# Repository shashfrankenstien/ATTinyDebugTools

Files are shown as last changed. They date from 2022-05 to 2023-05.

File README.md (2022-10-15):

# ATTiny85 Debug Tools

Arduino ISP, debugwire and charge pump based HVP for ATTiny85

-----

### This project is mostly based on code and circuits from [Wayne's Tinkering Page](https://sites.google.com/site/wayneholder/)

- [debugwire2](https://sites.google.com/site/wayneholder/debugwire2)
- [attiny-fuse-reset](https://sites.google.com/site/wayneholder/attiny-fuse-reset)
- [attiny-fuse-reset-with-12-volt-charge-pump](https://sites.google.com/site/wayneholder/attiny-fuse-reset-with-12-volt-charge-pump)

### Modified curcuit

- see AttinyDebugTools.fzz Fritzing file

<p align="center">
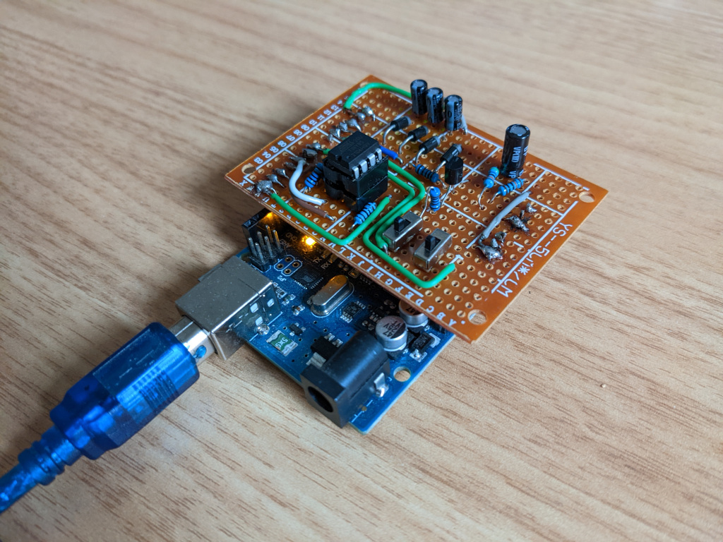
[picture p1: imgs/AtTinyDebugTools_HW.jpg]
  
</p>

### Usage

Can be started from Arduino Serial window, or using `serial_debugger.py`

```
 Commands:
  F - Identify Device & Print Fuses
  + - Enable debugWire DWEN Fuse
  - - Disable debugWire DWEN Fuse
  8 - Enable CKDIV8 (divide clock by 8)
  1 - Disable CKDIV8
  B - Engage Debugger
  < - Save Current Fuses
  > - Restore Saved Fuses
 High Voltage Programmer:
  R - Restore Saved Fuses (HVP)
  X - Hard Reset Fuses (HVP)
 Dev Commands:
  C - Send 4 Byte ISP Command
  P - Vcc On
  O - Vcc Off
```

### Also included, serial oscilloscope

- [arduino poor man's oscilloscope](https://randomnerdtutorials.com/arduino-poor-mans-oscilloscope/)

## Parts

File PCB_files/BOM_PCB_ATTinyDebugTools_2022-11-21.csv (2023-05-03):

ID | Name | Designator | Footprint | Quantity | Manufacturer Part | Manufacturer | Supplier | Supplier Part | Price | Pins | 3DModel | Contributor | Resistance (Ohms) | link
1 | 210S-1*10P L=11.6MMGold-plated black | H1 | HDR-TH_10P-P2.54-V-M-1 | 1 | B-2100S10P-A110 | Ckmtw(灿科盟) | LCSC | C124372 | 0.063 | 10 | HDR2.54-M-LI-1X10P | LCSC |  | https://item.szlcsc.com/58403.html
2 | 210-81-05GB01 | H2,H4,H3 | HDR-TH_5P-P2.54-V-M | 3 | 210-81-05GB01 | PINREX(频锐科技) | LCSC | C390676 | 0.029 | 5 | HDR-TH_5P-P2.54-M-LI-1X5P | LCSC |  | https://item.szlcsc.com/502960.html
3 | 1N4001_C2892326 | D1,D2,D3 | SOD-123FL_L2.8-W1.8-LS3.7-RD | 3 | 1N4001 | YONGYUTAI(永裕泰) | LCSC | C2892326 | 0.008 | 2 | SOD-123FL_L2.8-W1.8-LS3.7-RD | LCSC |  | https://atta.szlcsc.com/upload/public/pdf/source/20200828/C727068_03908989ABFAACA97C2BC5AF2D6316E6.pdf
4 | S8050_C2146 | Q1 | SOT-23-3_L3.0-W1.7-P0.95-LS2.9-BR | 1 | S8050 J3Y | CJ(江苏长电/长晶) | LCSC | C2146 | 0.016 | 3 | SOT-23-3L_L2.9-W1.6-H1.1-LS2.8-P0.95 | lcsc |  | https://item.szlcsc.com/139341.html
5 | 10kΩ | R1 | R0805 | 1 | 0805W8F1002T5E | UNI-ROYAL(厚声) | LCSC | C17414 | 0.001 | 2 | R0805_L2.0-W1.3-H0.6 | lcsc | 10K | https://item.szlcsc.com/142685.html
6 | 470kΩ | R2 | R0603 | 1 | 0603WAF4703T5E | UNI-ROYAL(厚声) | LCSC | C23178 | 0.001 | 2 | R0603_L1.6-W0.8-H0.8 | lcsc | 470K | https://www.mouser.in/datasheet/2/447/PYu_RT_1_to_0_01_RoHS_L_11-1669912.pdf
7 | 100kΩ | R3 | R0603 | 1 | 0603WAF1003T5E | UNI-ROYAL(厚声) | LCSC | C25803 | 0.001 | 2 | R0603_L1.6-W0.8-H0.8 | lcsc | 100K | https://www.mouser.in/datasheet/2/447/PYu_RT_1_to_0_01_RoHS_L_11-1669912.pdf
8 | 1kΩ | R4,R5,R6,R7 | R0603 | 4 | 0603WAF1001T5E | UNI-ROYAL(厚声) | LCSC | C21190 |  | 2 | R0603_L1.6-W0.8-H0.8 | lcsc | 1K | https://www.mouser.in/datasheet/2/447/PYu_RT_1_to_0_01_RoHS_L_11-1669912.pdf
9 | 220nF | C1,C2,C3 | CAP-SMD_L3.2-W1.6-RD | 3 | TAJA224K035RNJ | Kyocera AVX | LCSC | C11364 | 0.09 | 2 | CASE-A_L3.2-W1.6-H1.6 | lcsc |  | https://item.szlcsc.com/210648.html
10 | 2.2uF | C4 | CAP-SMD_L3.2-W1.6-RD | 1 | TAJA225K016RNJ | Kyocera AVX | LCSC | C7180 | 0.06 | 2 | CASE-A_L3.2-W1.6-H1.6 | lcsc |  | https://item.szlcsc.com/210648.html
11 | SS-3292S-L2-B | SW-PRG-DBG,SW-NORM-HVP | SW-SMD_SS-3292S-L2-B | 2 | SS-3292S-L2-B | XKB Enterprise | LCSC | C500057 | 0.132 | 7 | SW-SMD_SS-3292S-L2-B | LCSC |  | https://item.szlcsc.com/512183.html?ref=editor&logined=true
12 | DS1009-08AT1NX-0A2 | ATTINY | DIP-8_L10.0-W6.5-P2.54-LS7.6-BL | 1 | DS1009-08AT1NX-0A2 | CONNFLY | LCSC | C72124 | 0.031 | 8 | DIP-8_L10.0-W6.5-P2.54-LS7.6-BL | lcsc |  | https://item.szlcsc.com/241216.html

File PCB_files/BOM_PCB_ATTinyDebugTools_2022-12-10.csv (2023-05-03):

ID | Name | Designator | Footprint | Quantity | Manufacturer Part | Manufacturer | Supplier | Supplier Part | Price | Pins | 3DModel | Contributor | Resistance (Ohms) | link
1 | S4B-PH-K(LF)(SN) | I2C | CONN-TH_S4B-PH-K-LF-SN | 1 | S4B-PH-K(LF)(SN) | JST Sales America | LCSC | C265452 | 0.014 | 4 | CONN-TH_S4B-PH-K-LF-SN | LCSC |  | https://atta.szlcsc.com/upload/public/pdf/source/20180829/C265452_92616666173A3FAF5DFA68F980034548.pdf
2 | SS-3292S-L2-B | NORM-HVP,PRG-DBG | SW-SMD_SS-3292S-L2-B | 2 | SS-3292S-L2-B | XKB Enterprise | LCSC | C500057 | 0.021 | 7 | SW-SMD_SS-3292S-L2-B | LCSC |  | https://item.szlcsc.com/512183.html?ref=editor&logined=true
3 | 1N4148WS T4 | D1,D2,D3 | SOD-323_L1.8-W1.3-LS2.5-RD | 3 | 1N4148WS | CJ(江苏长电/长晶) | LCSC | C2128 | 0.002 | 2 | SOD-323_L1.7-W1.3-H1.1-LS2.5 | lcsc |  | https://item.szlcsc.com/295156.html
4 | 10kΩ | R1 | R0603 | 1 | 0603WAF1002T5E | UniOhm | LCSC | C25804 |  | 2 | R0603_L1.6-W0.8-H0.8 | lcsc | 10K | https://www.mouser.in/datasheet/2/447/PYu_RT_1_to_0_01_RoHS_L_11-1669912.pdf
5 | 220nF | C1,C2,C3 | C0603 | 3 | CL10B224KA8NNNC | SAMSUNG(三星) | LCSC | C21120 | 0.001 | 2 | C0603_L1.6-W0.8-H0.8 | lcsc |  | https://item.szlcsc.com/362304.html
6 | 2.2uF | C4 | C0603 | 1 | CL10A225KO8NNNC | SAMSUNG(三星) | LCSC | C23630 | 0.001 | 2 | C0603_L1.6-W0.8-H0.8 | lcsc |  | https://item.szlcsc.com/362304.html
7 | 1kΩ | R8,R4,R5,R6,R7 | R0603 | 5 | 0603WAF1001T5E | UNI-ROYAL(厚声) | LCSC | C21190 |  | 2 | R0603_L1.6-W0.8-H0.8 | lcsc | 1K | https://www.mouser.in/datasheet/2/447/PYu_RT_1_to_0_01_RoHS_L_11-1669912.pdf
8 | ARDUINO UNO | U1 | UNO_R3;WO ARDUINO UNO | 1 |  |  |  |  |  | 32
9 | S8050_C2146 | Q1 | SOT-23-3_L3.0-W1.7-P0.95-LS2.9-BR | 1 | S8050 J3Y | CJ(江苏长电/长晶) | LCSC | C2146 | 0.002 | 3 | SOT-23-3L_L2.9-W1.6-H1.1-LS2.8-P0.95 | lcsc |  | https://item.szlcsc.com/139341.html
10 | 470kΩ | R2 | R0603 | 1 | 0603WAF4703T5E | UNI-ROYAL(厚声) | LCSC | C23178 |  | 2 | R0603_L1.6-W0.8-H0.8 | lcsc | 470K | https://www.mouser.in/datasheet/2/447/PYu_RT_1_to_0_01_RoHS_L_11-1669912.pdf
11 | 100kΩ | R3 | R0603 | 1 | 0603WAF1003T5E | UNI-ROYAL(厚声) | LCSC | C25803 |  | 2 | R0603_L1.6-W0.8-H0.8 | lcsc | 100K | https://www.mouser.in/datasheet/2/447/PYu_RT_1_to_0_01_RoHS_L_11-1669912.pdf
12 | DS1009-08AT1NX-0A2 | ATTINY | DIP-8_L10.0-W6.5-P2.54-LS7.6-BL | 1 | DS1009-08AT1NX-0A2 | CONNFLY | LCSC | C72124 | 0.005 | 8 | DIP-8_L10.0-W6.5-P2.54-LS7.6-BL | lcsc |  | https://item.szlcsc.com/241216.html

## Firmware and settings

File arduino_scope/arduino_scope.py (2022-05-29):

import serial
import tkinter as tk
import time
from collections import deque, namedtuple


PORT = '/dev/ttyUSB0'
BAUD = 9600
AMPLITUDE_MAX = 1024
AMPLITUDE_MAX_VOLTAGE = 3.3 # volts
GRID_RESOLUTION = 0.5 # volts
GRID_RESOLUTION_PIXELS = GRID_RESOLUTION * AMPLITUDE_MAX / AMPLITUDE_MAX_VOLTAGE

DEFAULT_SPEED_SCALING = 2

WINDOW_HEIGHT = 500
WINDOW_WIDTH = 1400

root = tk.Tk()
root.geometry(f"{WINDOW_WIDTH}x{WINDOW_HEIGHT}")

Coord = namedtuple('Coord', ['x','y'])

def readInt(port):
    return int.from_bytes(port.read(), 'little')


def readTriplet(port):
    value = -1
    while (port.in_waiting >= 3):
        data = readInt(port)
        if (data == 255):
            value = (readInt(port) << 8) | (readInt(port))
    return value


def readQuintuplet(port):
    value = -1
    value2 = -1
    while (port.in_waiting >= 4):
        data = readInt(port)
        if (data == 255):
            value = (readInt(port) << 8) | (readInt(port))
            value2 = (readInt(port) << 8) | (readInt(port))
    return value, value2



def probe():
    with serial.Serial(PORT, BAUD, timeout=10) as port:
        while True:
            while not port.in_waiting:
                pass
            chan1, chan2 = readQuintuplet(port)
            if chan1 != -1 or chan2 != -1:
                yield chan1, chan2



class Stats(tk.Frame):
    def __init__(self, parent):
        super().__init__(parent, bd=5, bg="black")
        self.period = tk.StringVar(self.master, "-")
        self.freq = tk.StringVar(self.master, "-")
        self.bugs = tk.StringVar(self.master, "0 Bugs")
        self.bug_count = 0
        self.periods_for_mvavg = deque(maxlen=10)  # only holds 10 items

        label = tk.Label(self, textvariable=self.period, height=1, bg="black", fg="white", justify="right")
        label.pack()
        label = tk.Label(self, textvariable=self.freq, height=1, bg="black", fg="white", justify="right")
        label.pack()
        label = tk.Label(self, textvariable=self.bugs, height=1, bg="black", fg="white", justify="right")
        label.pack()


    def set_period(self, per):
        self.period.set(f"{per*1000:.2f} ms")
        self.freq.set(f"{1/per:.2f} Hz")
        self.periods_for_mvavg.append(per)
        if len(self.periods_for_mvavg) == 10:
            mvavg = sum(self.periods_for_mvavg) / 10
            if per / mvavg < 0.8 or per / mvavg > 1.2:
                self.bug_count += 1
                self.bugs.set(f"{self.bug_count} Bugs")
                # print(mvavg, per)



class WaveCanvas(tk.Canvas):

    def __init__(self, parent, width, height, x_scaling=DEFAULT_SPEED_SCALING):
        super().__init__(parent, bg='black', width=width, height=height, bd=0)
        self.height = height
        self.width = width
        self.x_scaling = x_scaling
        self.init_wave()
        self.pack(side='left')
        # self.draw_grid()
        self.zero = [
            (height / 4), # channel 0
            3 * (height / 4) # channel 1
        ]
        self.grid_lines = []


    def init_wave(self):
        size = int(self.width / self.x_scaling)
        self.wave = deque(maxlen=size)  # only holds width * self.x_scaling items
        for i in range(size):
            self.wave.append((0,0))

    def resize_wave(self, x_scaling):
        self.x_scaling = x_scaling
        size = int(self.width / self.x_scaling)
        old_wave = self.wave.copy()
        self.wave = deque(maxlen=size)  # only holds width * self.x_scaling items
        for i in range(min(size, len(old_wave))):
            self.wave.append(old_wave.popleft())

    def translate_y(self, y, channel):
        return self.zero[channel] - (y * (self.height/4) / AMPLITUDE_MAX )

    def draw_grid(self):
        if not self.grid_lines:
            for i in range(0, 7):
                self.grid_lines.append(self.translate_y(i * GRID_RESOLUTION_PIXELS, 0))
                self.grid_lines.append(self.translate_y(-i * GRID_RESOLUTION_PIXELS, 0))
                self.grid_lines.append(self.translate_y(i * GRID_RESOLUTION_PIXELS, 1))
                self.grid_lines.append(self.translate_y(-i * GRID_RESOLUTION_PIXELS, 1))

        for y in self.grid_lines:
            self.create_line(0, y, self.width, y, fill="#13330f", dash=(5,15))


    def draw(self):
        self.delete('all')
        prev_c1 = Coord(0, 0)
        prev_c2 = Coord(0, 0)
        for i, (chan1, chan2) in enumerate(self.wave.copy()):
            new_c1 = Coord(i * self.x_scaling, chan1)
            new_c2 = Coord(i * self.x_scaling, chan2)
            self.create_line(prev_c1.x, self.translate_y(prev_c1.y, 0), new_c1.x, self.translate_y(new_c1.y, 0), fill='green')
            self.create_line(prev_c2.x, self.translate_y(prev_c2.y, 1), new_c2.x, self.translate_y(new_c2.y, 1), fill='green')
            prev_c1 = new_c1
            prev_c2 = new_c2
        self.create_line(0, self.zero[0], self.width, self.zero[0], fill="#914646")
        self.create_line(0, self.zero[1], self.width, self.zero[1], fill="#914646")
        self.draw_grid()
        self.update()

    def append(self, signal):
        self.wave.append(signal)
        self.draw()



class Scope(tk.Frame):

    def __init__(self):
        super().__init__()
        self.plot_height = WINDOW_HEIGHT
        self.plot_width = WINDOW_WIDTH - 200

        self.init_ui()
        self.paused = False


    def init_ui(self):
        self.master.title("Oscilloscope")
        self.pack(fill='both', expand=1)

        self.canvas = WaveCanvas(self, height=self.plot_height, width=self.plot_width)

        self.ctrls = tk.Frame(self, bd=5, bg="black")
        self.stats = Stats(self.ctrls)
        self.stats.pack()
        extras = tk.Frame(self.ctrls, height=self.plot_height-20, bg="grey")

        self.pause_btn = tk.Button(extras, command=lambda : self.pause(), text="Pause")
        self.pause_btn.pack()

        self.closer_btn = tk.Button(extras, command=lambda : self.channels_closer(), text="closer")
        self.closer_btn.pack()
        self.farther_btn = tk.Button(extras, command=lambda : self.channels_farther(), text="farther")
        self.farther_btn.pack()

        self.faster_btn = tk.Button(extras, command=lambda : self.channels_faster(), text="faster")
        self.faster_btn.pack()

        self.slower_btn = tk.Button(extras, command=lambda : self.channels_slower(), text="slower")
        self.slower_btn.pack()

        extras.pack(fill="both", expand=True)
        self.ctrls.pack(side="left", fill="both", expand=True)

    def set_period(self, per):
        # bugs = self.stats.bug_count
        self.stats.set_period(per)
        # if bugs != self.stats.bug_count:
        #     self.pause()



    def start(self):
        gen = probe()
        st = 0
        prev_sig1 = 0
        prev_sig2 = 0

        def _update_task():
            nonlocal st, prev_sig1, prev_sig2

            if not self.paused:
                if st==0:
                    st = time.time()

                sig,sig2 = next(gen)

                if sig < (prev_sig1 / 5) and abs(sig-prev_sig1) > 10: # falling edge
                    self.set_period(time.time() - st)
                    st = 0
                try:
                    self.canvas.append((sig, sig2))
                except Exception as e:
                    print(e)
                    import traceback; traceback.print_exc()
                    return

                prev_sig1 = sig
            else:
                st = 0
                time.sleep(0.1)
            self.after(0, _update_task)

        _update_task()
        print("done")

    def pause(self):
        self.paused = not self.paused
        self.pause_btn['text'] = 'Play' if self.paused else 'Pause'


    # UI controls

    def channels_closer(self):
        self.canvas.zero[0] += 4
        self.canvas.zero[1] -= 4

    def channels_farther(self):
        self.canvas.zero[0] -= 4
        self.canvas.zero[1] += 4


    def channels_faster(self):
        self.canvas.resize_wave(self.canvas.x_scaling + 0.5)

    def channels_slower(self):
        self.canvas.resize_wave(self.canvas.x_scaling - 0.5)



if __name__ == '__main__':
    scope = Scope()
    scope.start()
    # root.protocol("WM_DELETE_WINDOW", scope.die)
    root.mainloop()

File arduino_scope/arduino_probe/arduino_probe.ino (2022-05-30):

///*
//  Complete project details: https://randomnerdtutorials.com/arduino-poor-mans-oscilloscope/
//*/
//
//#define ANALOG_IN 0
//
//void setup() {
//    Serial.begin(9600);
//    //Serial.begin(115200);
//}
//void loop() {
//    int val = analogRead(ANALOG_IN);
//    Serial.write( 0xff );
//    Serial.write( (val >> 8) & 0xff );
//    Serial.write( val & 0xff );
//}



#include "MCP3008.h"

//define pin connections
#define CLOCK_PIN 14
#define MISO_PIN 12
#define MOSI_PIN 13
#define CS_PIN 15


MCP3008 adc(CLOCK_PIN, MOSI_PIN, MISO_PIN, CS_PIN);

void setup()
{
 // open serial port
  Serial.begin(9600);
}

void loop()
{

  int val = adc.readADC(0); // read Channel 0 from MCP3008 ADC (pin 1)
  int val2 = adc.readADC(1); // read Channel 1 from MCP3008 ADC (pin 2)

  Serial.write( 0xff );
  Serial.write( (val >> 8) & 0xff );
  Serial.write( val & 0xff );
  Serial.write( (val2 >> 8) & 0xff );
  Serial.write( val2 & 0xff );
}

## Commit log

2022-03-26 working ISP, debugwire and charge pump based fuse reset features
    [circuit.fzz]
2022-03-26 update fritzing circuit diagram
    [ATTinyDebugTools.fzz, circuit.fzz]
2022-03-26 add fuse save and restore features
    [ATTinyDebugTools.fzz]
2022-03-27 yay, perf board programmer works + add python debugger
    [ATTinyDebugTools.fzz]
2022-04-04 add arduino oscilloscope + update serial debugger
2022-05-29 update asm constants print format
2022-10-15 update readme with circuit image
2023-05-03 add PCB gerber files
    [ATTinyDebugTools.fzz, BOM_PCB_ATTinyDebugTools_2022-11-21.csv, BOM_PCB_ATTinyDebugTools_2022-12-10.csv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]
